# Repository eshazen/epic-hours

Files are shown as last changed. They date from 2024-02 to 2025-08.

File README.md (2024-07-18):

# epic-hours

This is a project to create an electronic sign to display the opening
hours in EPIC.  Basic function is simple:  display open and close time
for each day of the week

There are (14) 8x24 matrix displays for open/close 7 days/week.
These use a special font to fit in the space:

    ten hours:   (blank) or 1
    one hours:   (blank) or 0-9
    ten minutes: (blank) or 0, 3
    one minutes: (blank) or 0

At the top there is a larger matrix, 8x64 which could display
a scrolling banner.

Each 8x8 matrix is driven by a MAX7219 controller IC.
See for example 
[documentation](https://lastminuteengineers.com/max7219-dot-matrix-arduino-tutorial/).

### LED version

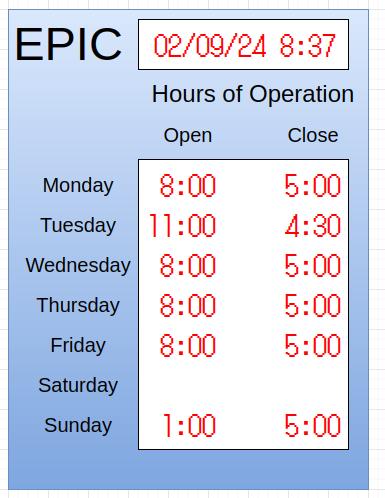
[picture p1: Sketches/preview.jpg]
Preview pixture


The first version should just be "boring" LEDs.  Probably LED matrix,
at least for a banner at the top so messages can be scrolled.
8x8 maxtrix are very popular, so thinking of a 5x7 font.
24 columns work for 12:34 displays.

Need a total of 42+8 = 50 of these.  This is about $100
for modules with MAX7219 included.

Power, 3 digits, quiescent (blanked) = 20mA.

| Intensity | mA  |
|---|-----|
| 3 | 154 |
| 2 | 118 |
| 1 | 80  |

Say 17 groups of 3 @ 150mA = 2.6A @ 5V

Standoffs:

    8   8-32 x 1 inch
	200 6-32 x 1/2 inch less than 0.22" OD

[Preview](Sketches/amazon_8x8.jpg)

### Development Notes

A pcb [multi_display_shield] https://github.com/eshazen/epic-hours/tree/main/KiCAD/multi_display_shield provides power distribution and control for 8
displays.  Each day is organized as a 8x48 single display,
with an 8x64 banner at the top.

For Wifi:  propose to use an ESP32 30-pin dev board.  
See (this page)[https://lastminuteengineers.com/esp32-pinout-reference/]
for some very useful notes.

### Software / Interface

Use Arduino Uno as display controller.  Serial command set:

	T n hh:mm hh:mm   - Time - set weekday time (0,1 = Mon, 2,3 = Tue etc)
	                           for opening and closing
	M text...         - Banner - set banner text.  Scroll if too long
    I n               - Intensity - set intensity n=0-7

ESP32 connects to eduroam WiFi and handles queries such as:

http://10.239.25.67/CMD=M%20Welcome%20to%20EPIC

Everything after the "CMD=" is percent-decoded and sent to the Arduino.

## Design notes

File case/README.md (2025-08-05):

# Enclosure design

Notes for design:

Assembly is a stack of two 3mm acrylic sheets 17-3/4 x 11-5/8 inches.
<br>Spacing varies but is about 1" c-c.
<br>A slot 1-1/24 would do it.

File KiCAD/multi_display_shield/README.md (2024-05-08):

# Multi-Display Shield

This is a very simple Arduino shield which allows driving of up to 8
LED displays based on the MAX7219 or similar SPI-based driver.
The board fans out `MOSI` and `SCK` to all boards using '244 drivers, and
provides separate `CS` signals to each.

## ECOs

* Jumper U1 pin 2-4

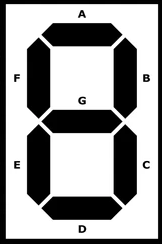
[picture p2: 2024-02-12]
Sketches/7seg.png

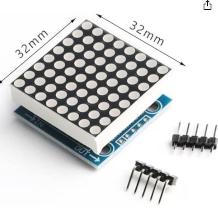
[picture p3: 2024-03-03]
Sketches/amazon_8x8.jpg

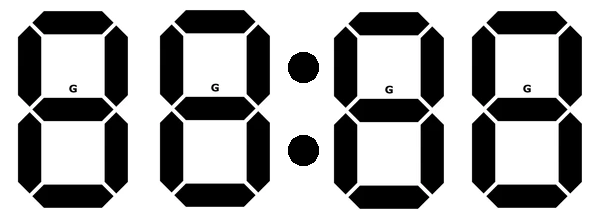
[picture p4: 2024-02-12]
Sketches/7seg-time.png

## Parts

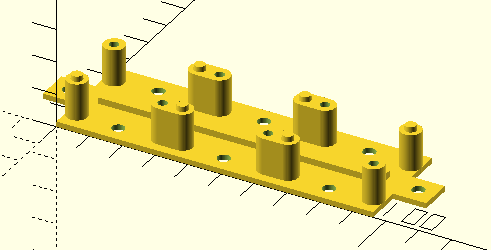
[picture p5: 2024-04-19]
parts/display_standoffs_screenshot.png

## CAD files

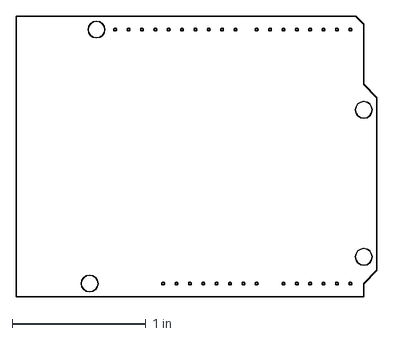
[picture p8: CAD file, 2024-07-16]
parts/Arduino UNO R3 shield - full.dxf
2.70 x 2.10 in

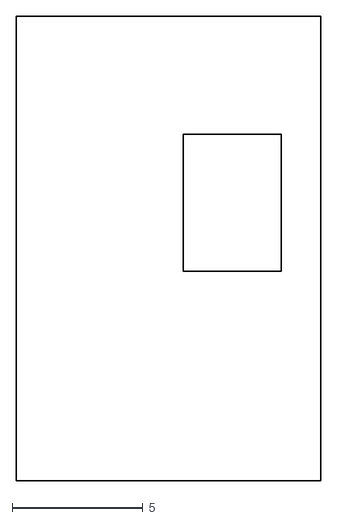
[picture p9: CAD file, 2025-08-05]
case/back_view_outline.dxf
11.6 x 17.8

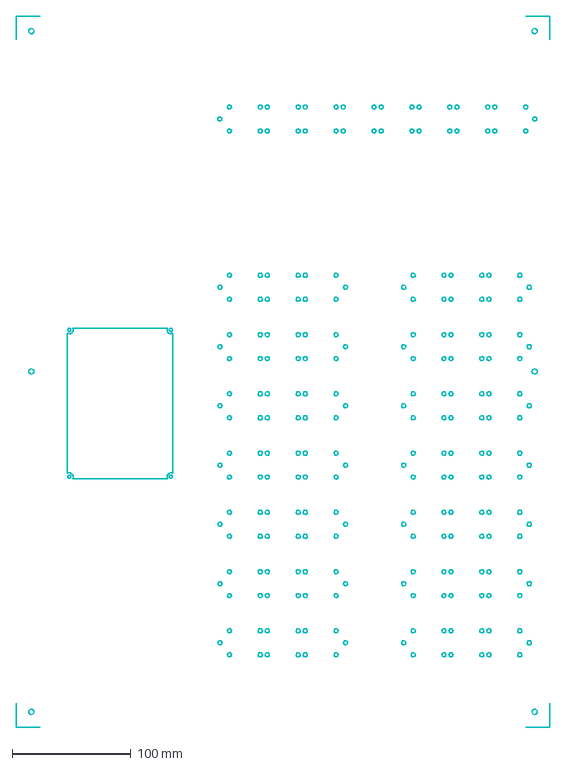
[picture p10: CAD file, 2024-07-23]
laser_cut/cut_back.dxf
450.0 x 600.0 mm

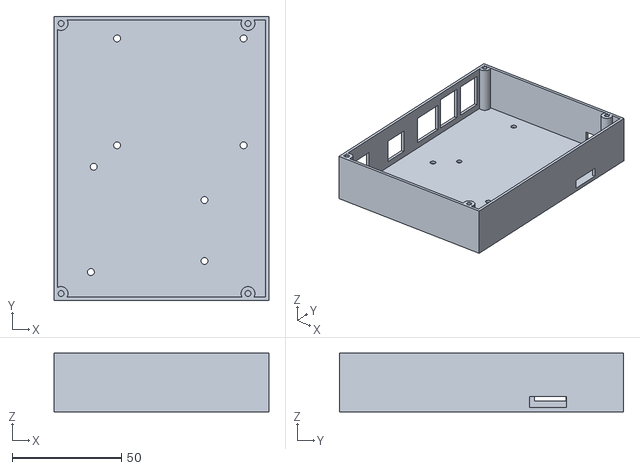
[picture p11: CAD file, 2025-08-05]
parts/rpi_box.stl
98.4 x 130.2 x 27.0

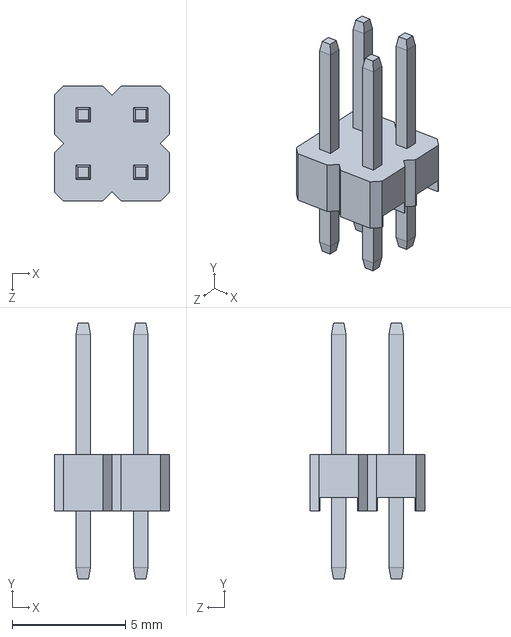
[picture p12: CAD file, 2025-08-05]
parts/rpi_model/2.54 mm DUPONT MALE PIN HEADER, POE, 2X2, RPi4ModelB.SLDPRT
5.08 x 11.3 x 5.08 mm

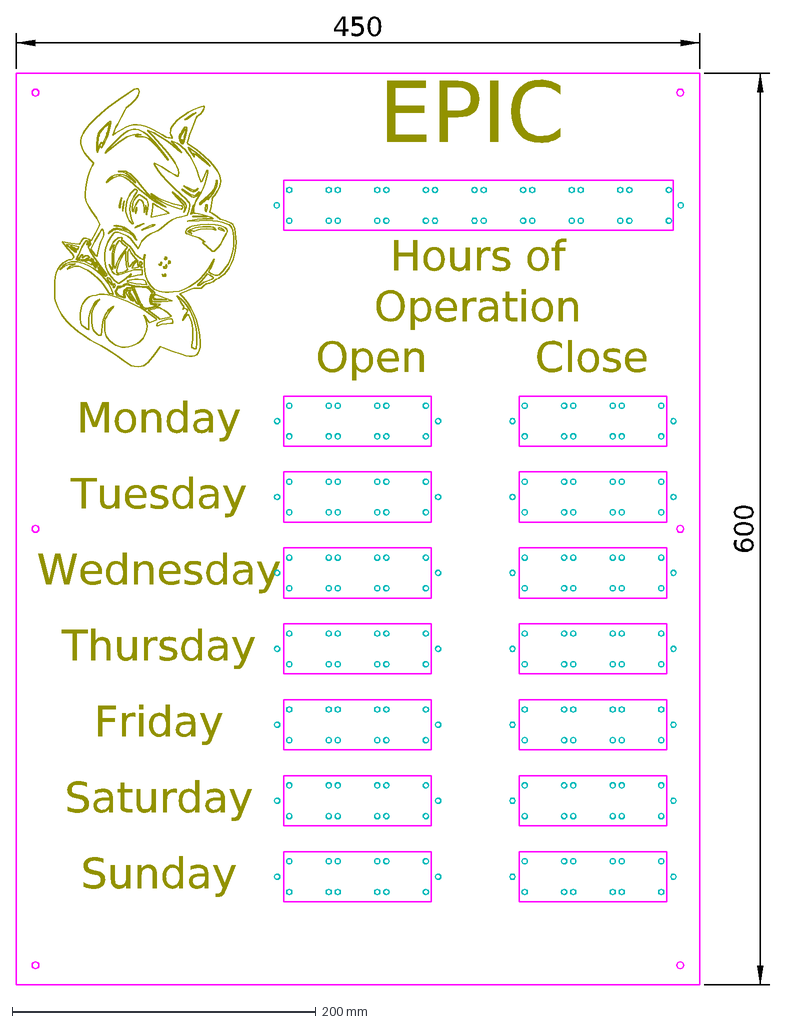
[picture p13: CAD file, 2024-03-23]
Sketches/layout_450x600.dxf
Open
Hours of Operation
Wednesday
Monday
Tuesday
Thursday
Friday
Saturday
Sunday
EPIC
Close
450
600

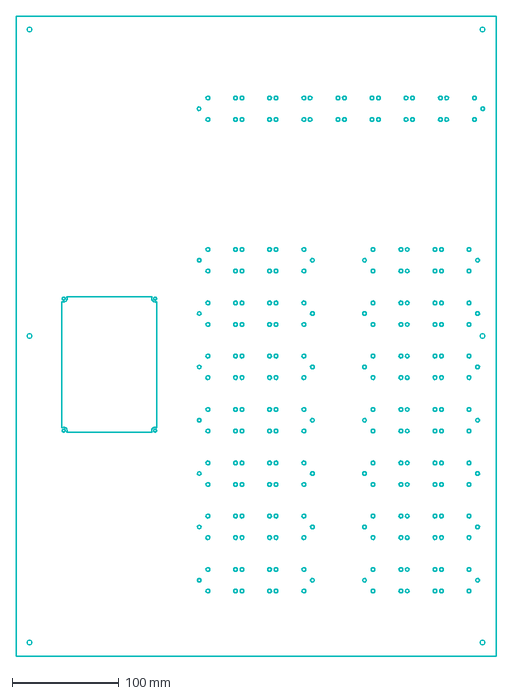
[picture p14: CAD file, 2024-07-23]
laser_cut/cut_back_with_outline.dxf
450.0 x 600.0 mm

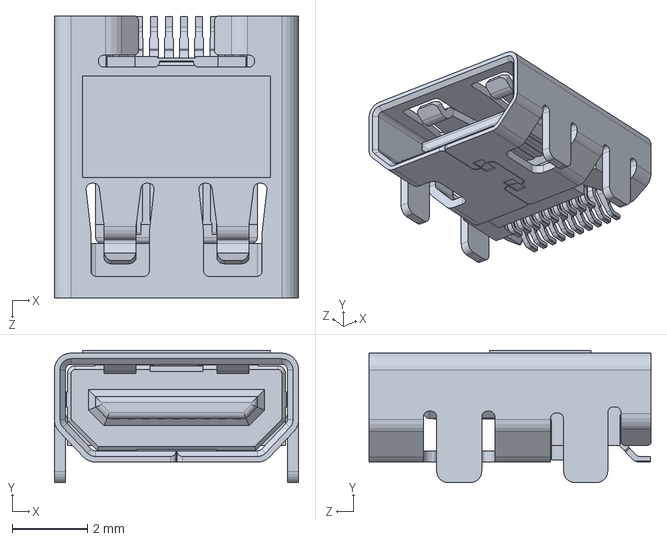
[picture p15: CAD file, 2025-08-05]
parts/rpi_model/Female Micro HDMI Connector, RPi4ModelB.SLDPRT
6.50 x 3.52 x 7.50 mm

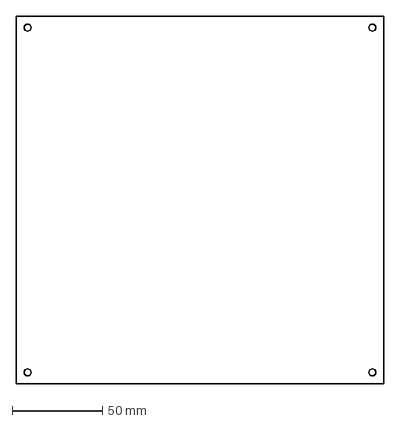
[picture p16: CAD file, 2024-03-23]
Sketches/test_8x8.dxf
203.2 x 203.2 mm

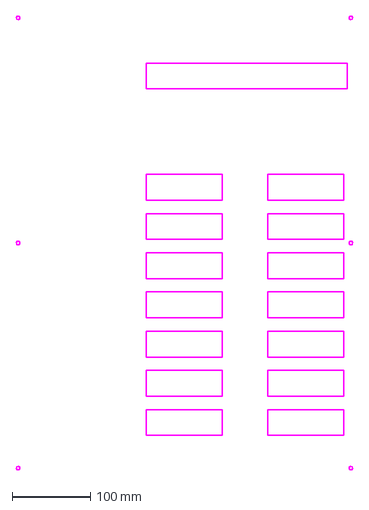
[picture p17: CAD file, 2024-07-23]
laser_cut/cut_front_with_outline.dxf
429.1 x 579.1 mm

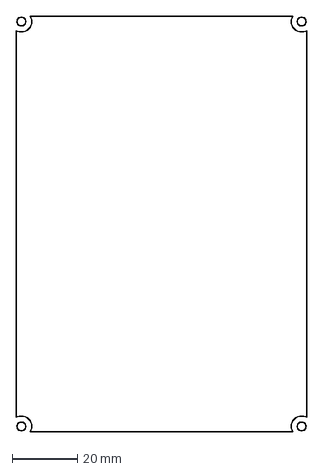
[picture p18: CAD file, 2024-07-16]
parts/arduino_box_opening.dxf
88.9 x 127.0 mm

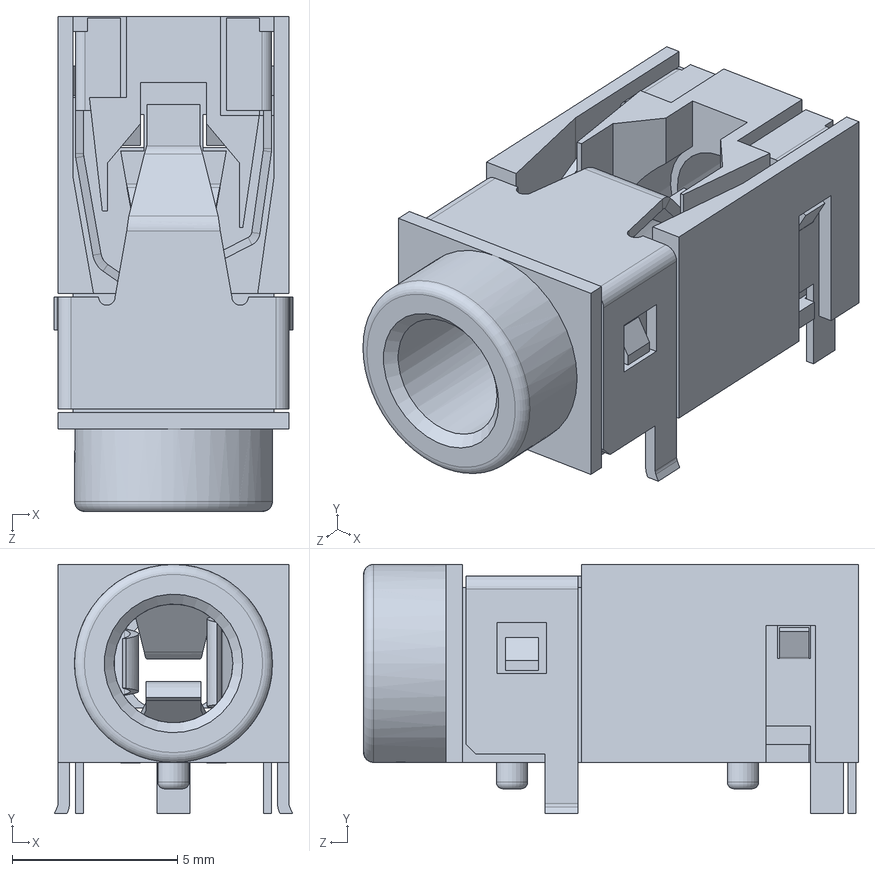
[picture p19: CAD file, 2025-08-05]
parts/rpi_model/Microphone Plug, RPi4ModelB.SLDPRT
7.23 x 7.55 x 15.0 mm

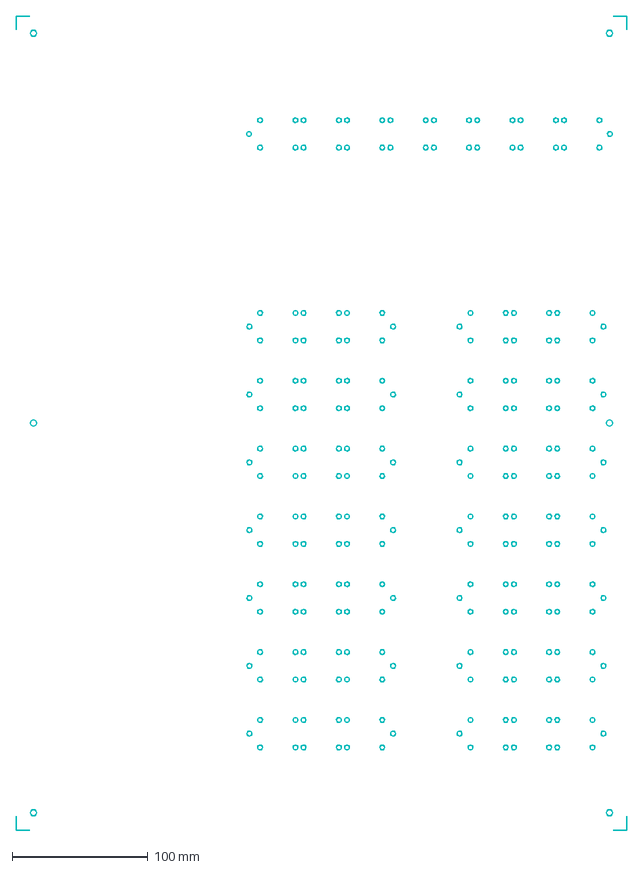
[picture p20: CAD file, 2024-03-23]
Sketches/cut_back.dxf
450.0 x 600.0 mm

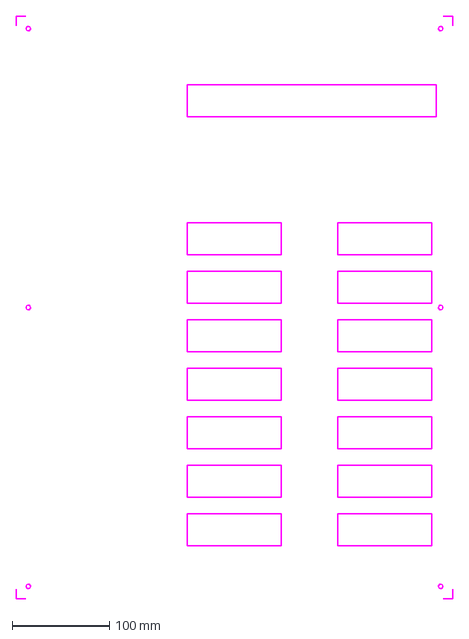
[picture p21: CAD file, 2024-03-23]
laser_cut/cut_front.dxf
450.0 x 600.0 mm

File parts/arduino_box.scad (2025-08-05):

//
// Arduino box, in mm
//

$fn=32;
e=0.1;
mm=25.4;


ardu_x = 0.05*mm;
ardu_y = 0.35*mm;
ardu_dy = 2.25*mm;
ardu_so = 0.125*mm;

flange_w = 0.5*mm;
fh_off = 0.25*mm;
flange_hole_dia = 0.15*mm;
ardu_hole_dia = 0.125*mm;

cavity_wid = 3.5*mm;
cavity_len = 5*mm;
cavity_hgt = 1*mm;
// cavity_hgt = 0.25*mm;

thk = 1.6;

// flange_w = 0.25*mm;
// fh_off = 0.125*mm;
// flange_hole_dia = 0.1*mm;
// ardu_hole_dia = 0.125*mm;
// 
// cavity_wid = 1*mm;
// cavity_len = 1*mm;
// cavity_hgt = 0.5*mm;
// thk = .063*mm;

module hole_at( x, y, d) {
  translate( [x, y, -e])
    cylinder( h=3*mm, d=d);
}

// arduino/shield mounting holes
module ardu_holes( x, y) {
  translate( [x, y, 0]) {
    hole_at( 0.55*mm,  0.1*mm, ardu_hole_dia);
    hole_at( 0.601*mm, 2*mm, ardu_hole_dia);
    hole_at( 2.601*mm, 1.4*mm, ardu_hole_dia);
    hole_at( 2.601*mm, 0.3*mm, ardu_hole_dia);
  }
}

// bottom with mounting holes
module bottom() {
  difference() {
    cube( [cavity_wid, cavity_len, thk]);
    ardu_holes( ardu_x, ardu_y);
    ardu_holes( ardu_x, ardu_y+2.25*mm);
  }
}

// clearance around cutouts
spc = 0.05*mm;

module ardu_cutouts() {
  // USB connector
  translate( [-6, 32+spc, pcb_thk-spc])
    cube( [16, 11.5+2*spc, 10.5+2*spc]);
  // power barrel jack
  color("black") {
    translate( [-6, 3.5+spc, pcb_thk-spc])
      cube( [10, 8.5+2*spc, 11+2*spc]);
  }
}

module ardu_cuts() {
  translate( [ardu_x, ardu_y, thk+ardu_so]) {
    ardu_cutouts();
    translate( [0, ardu_dy, 0])
      ardu_cutouts();
  }
}



// box with cavity
module box() {
  translate( [-thk, -thk, 0]) {
    difference() {
      cube( [cavity_wid+2*thk, cavity_len+2*thk, cavity_hgt+thk]);
      translate( [thk, thk, -e])
	cube( [cavity_wid, cavity_len, cavity_hgt+2*e+thk]);
      ardu_cuts();
    }
  }
}

// flange
max_wid = cavity_wid+2*flange_w;
max_len = cavity_len+2*flange_w;

module flange() {
  translate( [-flange_w, -flange_w, cavity_hgt]) {
    difference() {
      cube( [max_wid, max_len, thk]);
      translate( [flange_w, flange_w, -e])
	cube( [cavity_wid, cavity_len, thk+2*e]);
      hole_at( fh_off, fh_off, flange_hole_dia);
      hole_at( max_wid-fh_off, fh_off, flange_hole_dia);
      hole_at( fh_off, max_len-fh_off, flange_hole_dia);
      hole_at( max_wid-fh_off, max_len-fh_off, flange_hole_dia);
    }
  }
}

so_dia = 0.25*mm;
so_hol = 0.106*mm;

module so_at(x, y) {
  translate( [x, y, thk-e]) {
    difference() {
      cylinder( d=so_dia, h=cavity_hgt);
      translate( [0, 0, thk])
	cylinder( d=so_hol, h=cavity_hgt);
    }
  }
    
}

module standoffs() {
  so_at( thk, thk);
  so_at( cavity_wid-thk, thk);
  so_at( cavity_wid-thk, cavity_len-thk);
  so_at( thk, cavity_len-thk);
}

pcb_thk = 1.6;

module arduino() {
  color("blue")
    linear_extrude( height=pcb_thk)
      scale( [mm, mm, mm]) import("arduino_outline.dxf");
  // USB connector
  translate( [-6, 32, pcb_thk])
    color("gray") cube( [16, 11.5, 10.5]);
  // power barrel jack
  color("black") {
    translate( [-2, 3.5, pcb_thk])
      cube( [3, 8.5, 11]);
    translate( [0, 7.75, 6])
    rotate( [0, 90, 0])
      cylinder( d=8, h=10);
  }
}

module arduinos() {
  translate( [ardu_x, ardu_y, thk+ardu_so]) {
    arduino();
    translate( [0, ardu_dy, 0])
      arduino();
  }
}

module assembly() {
  bottom();
  box();
  standoffs();
}

// projection( cut=true) translate( [0, 0, -10])  
assembly();

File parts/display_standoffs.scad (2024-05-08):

//
// support bracket for 8x8 displays
//

// ToDo:
//   Stiffener ridge down middle
//   Mount tabs at ends
//

$fn = 64;
e = 0.1;
mm = 25.4;

include <post.scad>;

bracket_wid = 32;		/* width of one panel */
bracket_len = 9;		/* bracket width (in Y) */
bracket_hgt = 1.6;		/* thickness of base */

total_hgt = 0.5*mm;		/* overall bracket height (base to pcb) */

// mounting hole diameter
hole_dia = 0.15*mm;

// hole in center of post (for #4 sheet metal screw)
// post_hole = 0.150*mm;
post_hole_dia = 0.11*mm;

// post locations
post_dx = 3;
posts1 = [ [post_dx, 5.9], [32-post_dx, 32-5.9] ];
posts2 = [ [32-post_dx, 5.9], [post_dx, 32-5.9] ];

post_spc_x = 32-2*post_dx;
post_spc_y = 32-2*5.9;

// stiffener
stiff_thk = 5;
stiff_hgt = 2;
stiff_gap = 5;

// end mounting tabs
tab_wid = 0.4*mm;

// mounting hole
module hole_at( x, y, d) {
     translate( [x, y, -e])
	  cylinder( d=d, h=bracket_hgt+2*e);
}

module post_hole( x, y) {
     translate( [x, y, -10])
	  cylinder( h=30, d=post_hole_dia);

}

module tab_at( x, y) {
  translate( [x, y, 0]) {
    difference() {
	 cube( [tab_wid+e, tab_wid, bracket_hgt]);
	 hole_at( tab_wid/2, tab_wid/2, hole_dia);
       }
  }
}


module bracket() {
     difference() {
	  union() {
	       cube( [bracket_wid+e, bracket_wid+e, bracket_hgt]);
	       for( pt = posts1) {
		 post_at( pt.x, pt.y, 1);
	       }
	       for( pt = posts2) {
		 post_at( pt.x, pt.y, 0);
	       }
	  }
	  hole_at( bracket_wid/2, 0.2*mm, hole_dia);
	  hole_at( bracket_wid/2, bracket_wid-0.2*mm, hole_dia);
	  for( pt = posts2) {
	       post_hole( pt.x, pt.y);
	  }
     }
}

// set of <ndigit> brackets
module multi_bracket(ndigit) {
     for( i=[0:ndigit-1]) {
	  translate( [i*bracket_wid, 0, 0])
	       bracket();
     }
     // bridges between standoffs
     if( ndigit > 1) {
	  p1 = posts2[0];
	  p2 = posts1[1];
	  for( i=[0:ndigit-2]) {
	       // offset to bracket
	       translate( [i*bracket_wid, 0, 0]) {
		    // draw the bridge, then re-drill the holes
		    difference() {
			 translate( [p1.x, p1.y-peg_dia/2, 0])
			      cube( [peg_dia, peg_dia, total_hgt]);
			 post_hole( p1.x, p1.y);
			 post_hole( p1.x+2*post_dx, p1.y);
		    }
		    difference() {
			 translate( [p2.x, p2.y-peg_dia/2, 0])
			      cube( [peg_dia, peg_dia, total_hgt]);
			 post_hole( p2.x, p2.y);
			 post_hole( p2.x+2*post_dx, p2.y);
		    }
	       }
	  }
     }

     // stiffener
     translate( [stiff_gap, bracket_wid/2-stiff_thk/2, bracket_hgt-e])
       cube( [ndigit*bracket_wid-2*stiff_gap, stiff_thk, stiff_hgt]);

     // end mounting tabs
     tab_at( -tab_wid, bracket_wid/2-tab_wid/2);
     tab_at( ndigit*bracket_wid-e, bracket_wid/2-tab_wid/2);
       
}

// single peg for testing
module test_peg() {
     difference() {
       post_at( 5, 5, 0);
	  post_hole( 5,5);
     }
     post_at( 5+post_spc_x, 5, 1);
     difference() {
       cube( [bracket_wid+5, 10, bracket_hgt]);
       post_hole( 5, 5);
     }
}

// two multi_bracket() with spacing
module multi_assembly( nb, dx) {
     multi_bracket(nb);
     translate( [dx, 0, 0])
	  multi_bracket(nb);
     translate( [bracket_wid*nb, 0, 0])
	  cube( [dx-nb*bracket_wid, bracket_wid, bracket_hgt]);
}

// projection()
// rotate( [90, 0, 0])
// rotate( [0, 0, 45])
multi_bracket(8);
// multi_assembly( 3, 155);



// test_peg();

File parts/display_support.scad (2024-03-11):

//
// support bracket for 8x8 displays
//

$fn = 64;
e = 0.1;
mm = 25.4;

include <post.scad>;

ndigit = 1;

bracket_wid = 32;		/* width of one panel */
bracket_len = 9;		/* bracket width (in Y) */
bracket_hgt = 1;

total_hgt = 0.5*mm;		/* overall bracket height (back to pcb) */

hole_dia = 0.15*mm;

// mounting hole
module hole_at( x, y) {
     translate( [x, y, -e])
	  cylinder( d=hole_dia, h=bracket_hgt+2*e);
}

module bracket() {
     difference() {
	  cube( [bracket_wid+e, bracket_wid+e, bracket_hgt]);
	  hole_at( bracket_wid/2, 0.2*mm);
	  hole_at( bracket_wid/2, bracket_wid-0.2*mm);
     }
     post_at( 3, 5.9);
     post_at( 32-3, 5.9);
     post_at( 3, 32-5.9);
     post_at( 32-3, 32-5.9);
}

// set of <ndigit> brackets
module multi_bracket() {
     for( i=[0:ndigit-1]) {
	  translate( [i*bracket_wid, 0, 0])
	       bracket();
     }
}

// single peg for testing
module test_peg() {
     post_at( 5, 5);
}

// multi_bracket();


test_peg();

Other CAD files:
parts/#arduino_box_all.dxf
Sketches/cut_back_holes.dxf
parts/post.scad
Sketches/7seg-mech.scad
Sketches/7seg_digit.dxf
Sketches/front_panel.dxf
Sketches/layout_8x8.dxf
parts/8display_standoffs.stl
parts/arduino_box.stl
parts/arduino_box_all.dxf
parts/arduino_box_cutout.dxf
parts/arduino_outline.dxf
parts/display_standoffs.dxf
parts/display_standoffs.stl
parts/display_standoffs_8x.dxf
parts/display_standoffs_side.dxf
parts/display_support.stl
parts/post.stl
parts/rpi_box.scad
parts/rpi_model/2X USB2.0 PORTS, RPi4ModelB.SLDPRT
parts/rpi_model/2X USB3.0 PORTS, RPi4ModelB.SLDPRT
parts/rpi_model/Broadcom BCM2711B0 CPU, RPi4ModelB.SLDPRT
parts/rpi_model/Broadcom BCM54213PE Gigabit Ethernet Transceiver, RPi4ModelB.SLDPRT
parts/rpi_model/Cypress CYW43455 Wireless Module Cover, RPi4ModelB.SLDPRT
parts/rpi_model/Display Connector, RPi4ModelB.SLDPRT
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

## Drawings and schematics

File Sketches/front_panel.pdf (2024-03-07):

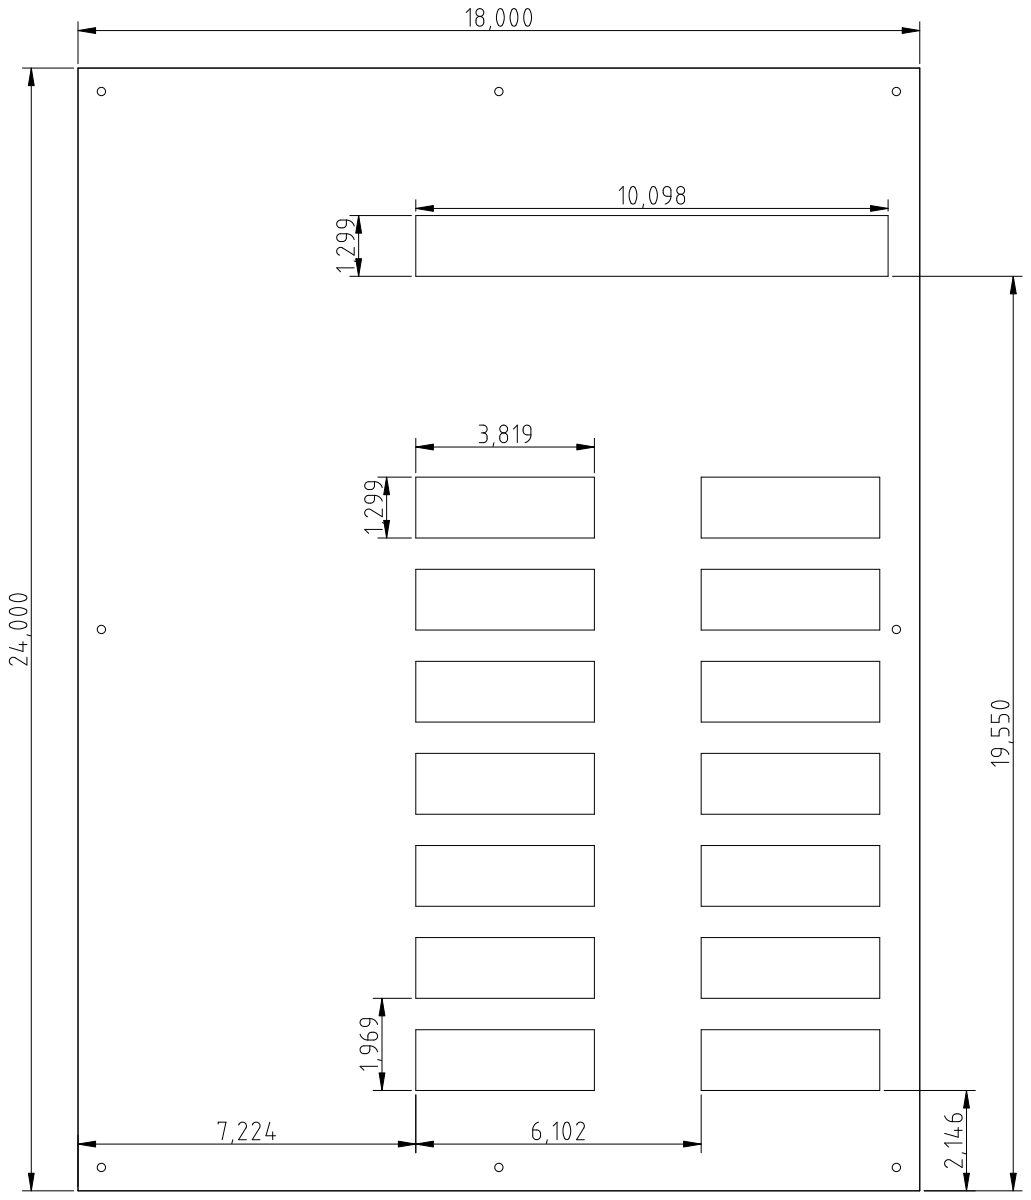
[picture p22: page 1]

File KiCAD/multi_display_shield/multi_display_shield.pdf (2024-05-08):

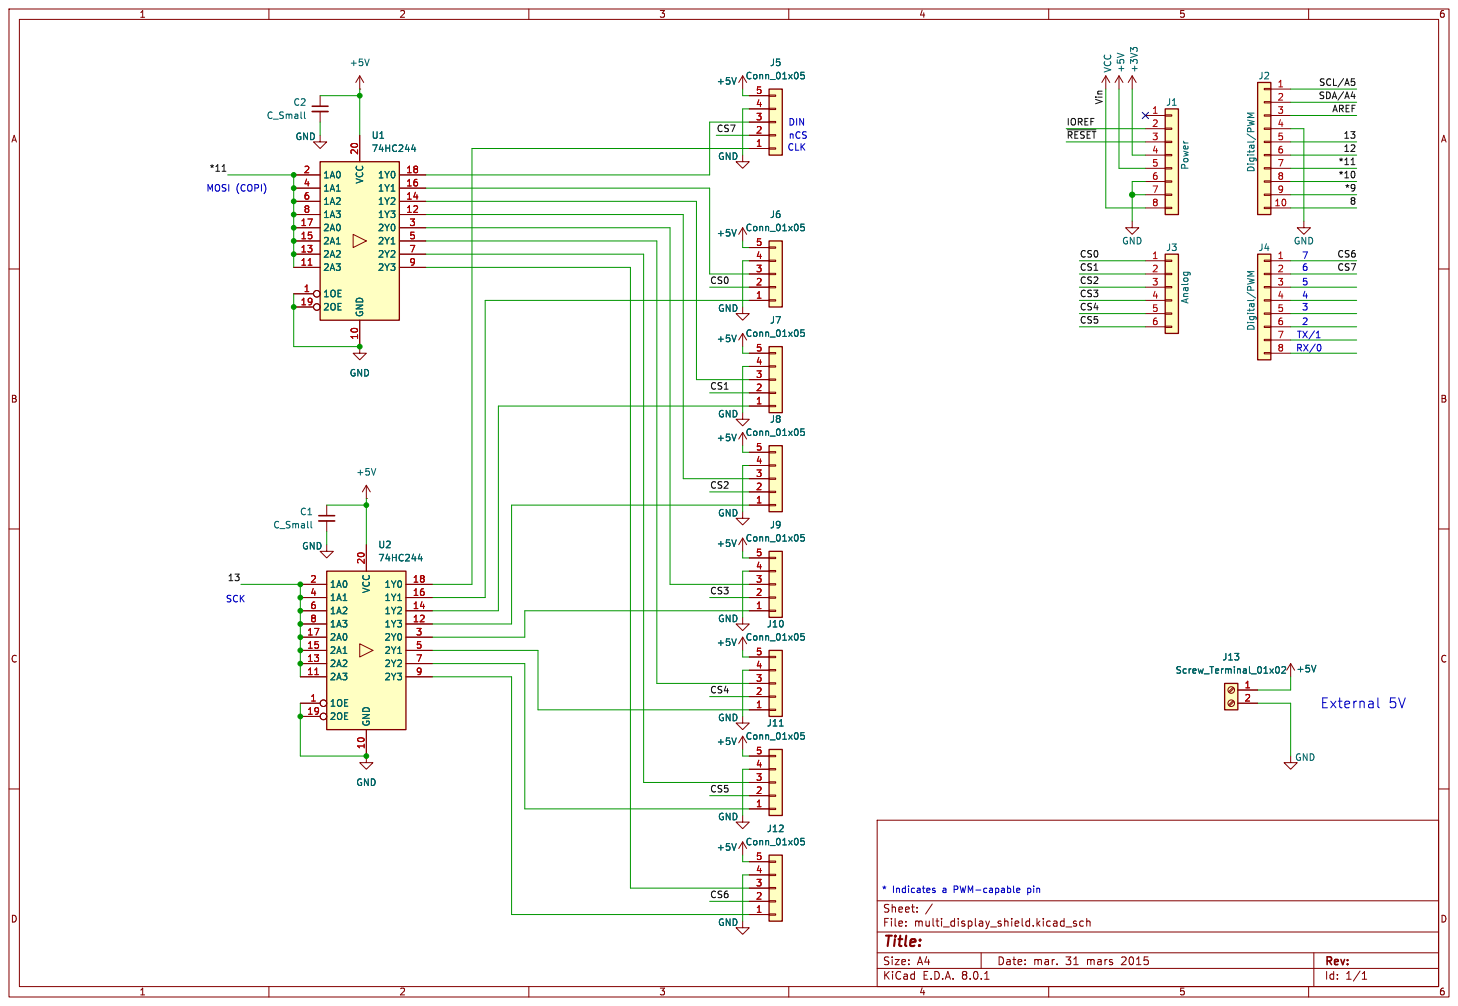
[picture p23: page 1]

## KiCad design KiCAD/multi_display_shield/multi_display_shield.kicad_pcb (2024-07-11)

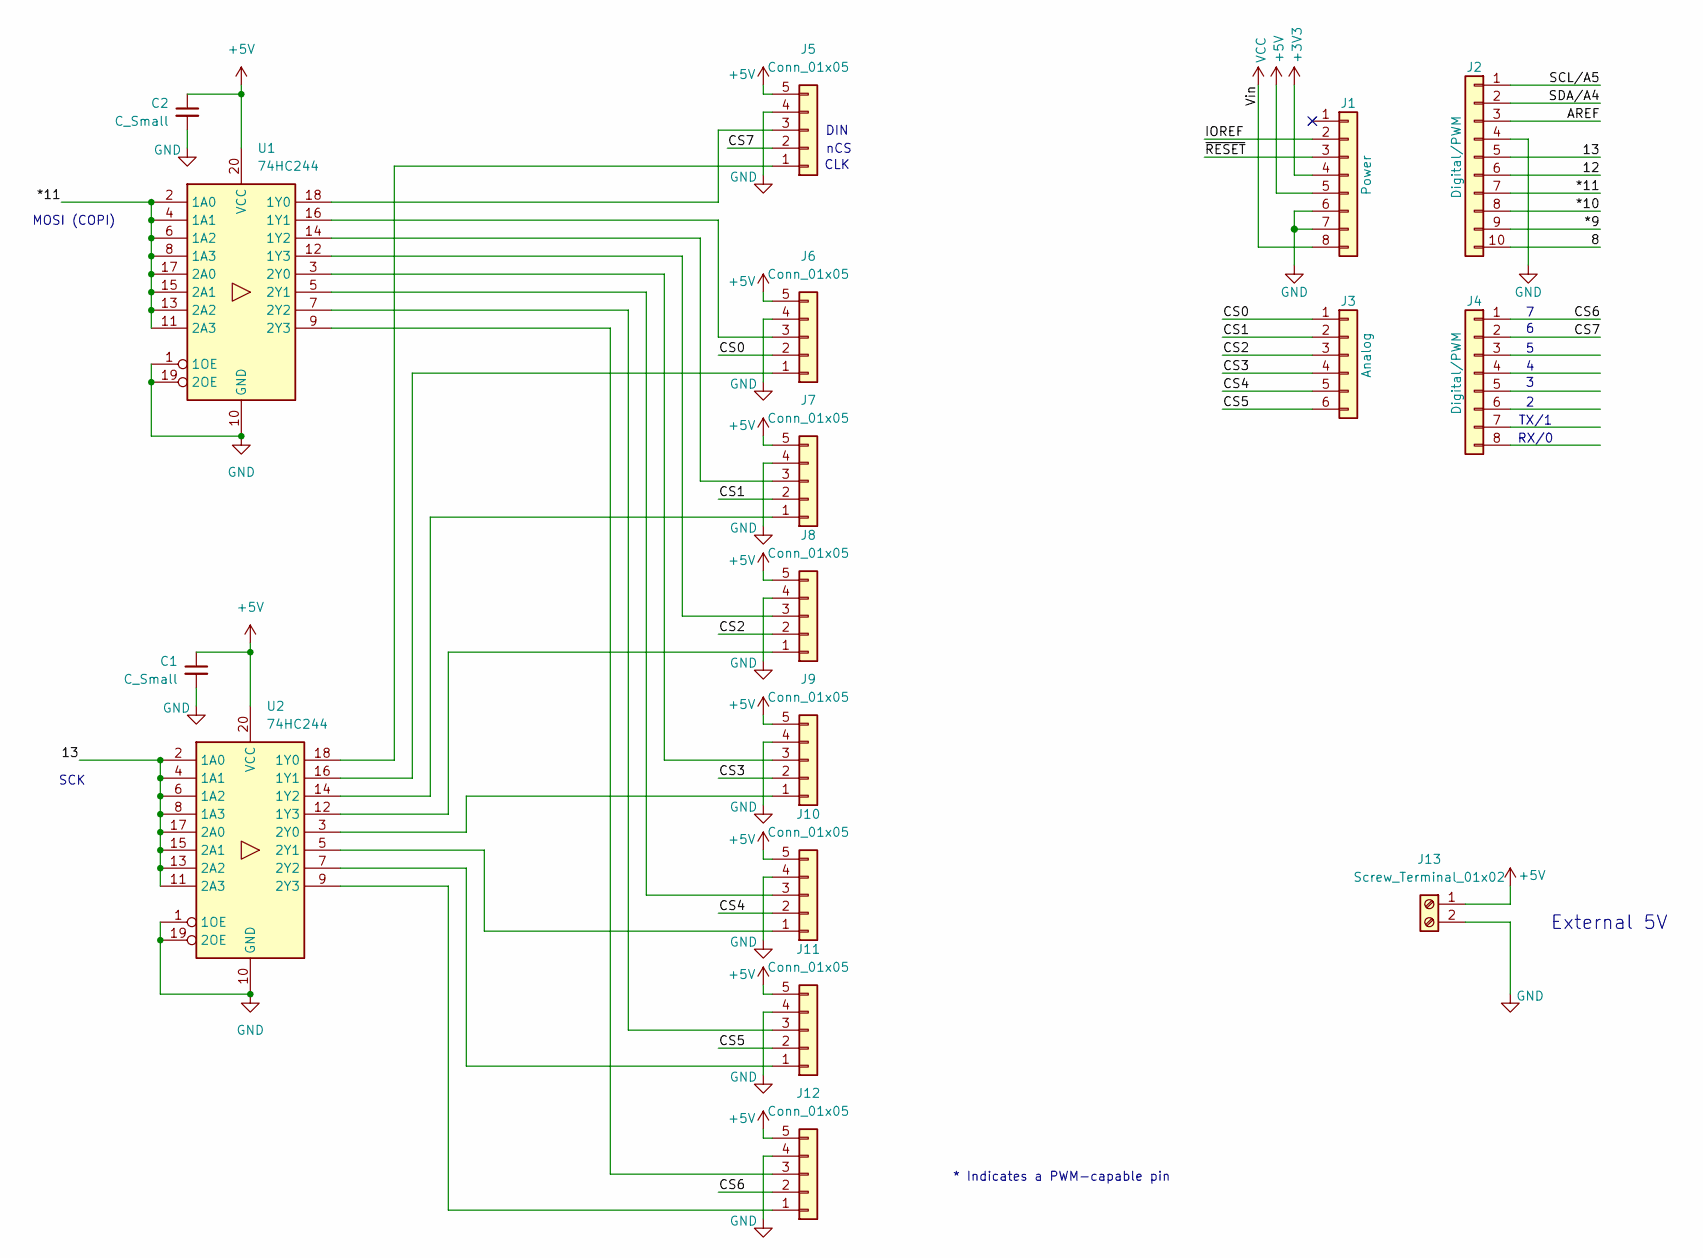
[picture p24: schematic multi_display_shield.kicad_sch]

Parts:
C1, C2: C_Small; C_Rect_L7.0mm_W2.5mm_P5.00mm
J1: Power; PinSocket_1x08_P2.54mm_Vertical
J2: Digital/PWM; PinSocket_1x10_P2.54mm_Vertical
J3: Analog; PinSocket_1x06_P2.54mm_Vertical
J4: Digital/PWM; PinSocket_1x08_P2.54mm_Vertical
J5, J6, J7, J8, J9, J10, J11, J12: Conn_01x05; PinHeader_1x05_P2.54mm_Vertical
J13: Screw_Terminal_01x02; Wago_734-132_1x02_P3.50mm_Vertical
U1, U2: 74HC244; DIP-20_W7.62mm

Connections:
+3V3: J1.4
+5V: C1.1, C2.1, J1.5, J5.5, J6.5, J7.5, J8.5, J9.5, J10.5, J11.5, J12.5, J13.1, U1.20 (VCC), U2.20 (VCC)
/8: J2.10
/12: J2.6
/13: J2.5, U2.2 (1A0), U2.4 (1A1), U2.6 (1A2), U2.8 (1A3), U2.11 (2A3), U2.13 (2A2), U2.15 (2A1), U2.17 (2A0)
/*9: J2.9
/*10: J2.8
/*11: J2.7, U1.2 (1A0), U1.4 (1A1), U1.6 (1A2), U1.8 (1A3), U1.11 (2A3), U1.13 (2A2), U1.15 (2A1), U1.17 (2A0)
/AREF: J2.3
/CS0: J3.1, J6.2
/CS1: J3.2, J7.2
/CS2: J3.3, J8.2
/CS3: J3.4, J9.2
/CS4: J3.5, J10.2
/CS5: J3.6, J11.2
/CS6: J4.1, J12.2
/CS7: J4.2, J5.2
/IOREF: J1.2
/SCL/A5: J2.1
/SDA/A4: J2.2
/~RESET: J1.3
GND: C1.2, C2.2, J1.6, J1.7, J2.4, J5.4, J6.4, J7.4, J8.4, J9.4, J10.4, J11.4, J12.4, J13.2, U1.1 (1OE), U1.10 (GND), U1.19 (2OE), U2.1 (1OE), U2.10 (GND), U2.19 (2OE)
unnamed: J5.1, U2.18 (1Y0)
unnamed: J5.3, U1.18 (1Y0)
unnamed: J6.1, U2.16 (1Y1)
unnamed: J6.3, U1.16 (1Y1)
unnamed: J7.1, U2.14 (1Y2)
unnamed: J7.3, U1.14 (1Y2)
unnamed: J8.1, U2.12 (1Y3)
unnamed: J8.3, U1.12 (1Y3)
unnamed: J9.1, U2.3 (2Y0)
unnamed: J9.3, U1.3 (2Y0)
unnamed: J10.1, U2.5 (2Y1)
unnamed: J10.3, U1.5 (2Y1)
unnamed: J11.1, U2.7 (2Y2)
unnamed: J11.3, U1.7 (2Y2)
unnamed: J12.1, U2.9 (2Y3)
unnamed: J12.3, U1.9 (2Y3)
VCC: J1.8

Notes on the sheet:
CLK
SCK
* Indicates a PWM-capable pin
RX/0
MOSI (COPI)
nCS
DIN
TX/1
External 5V

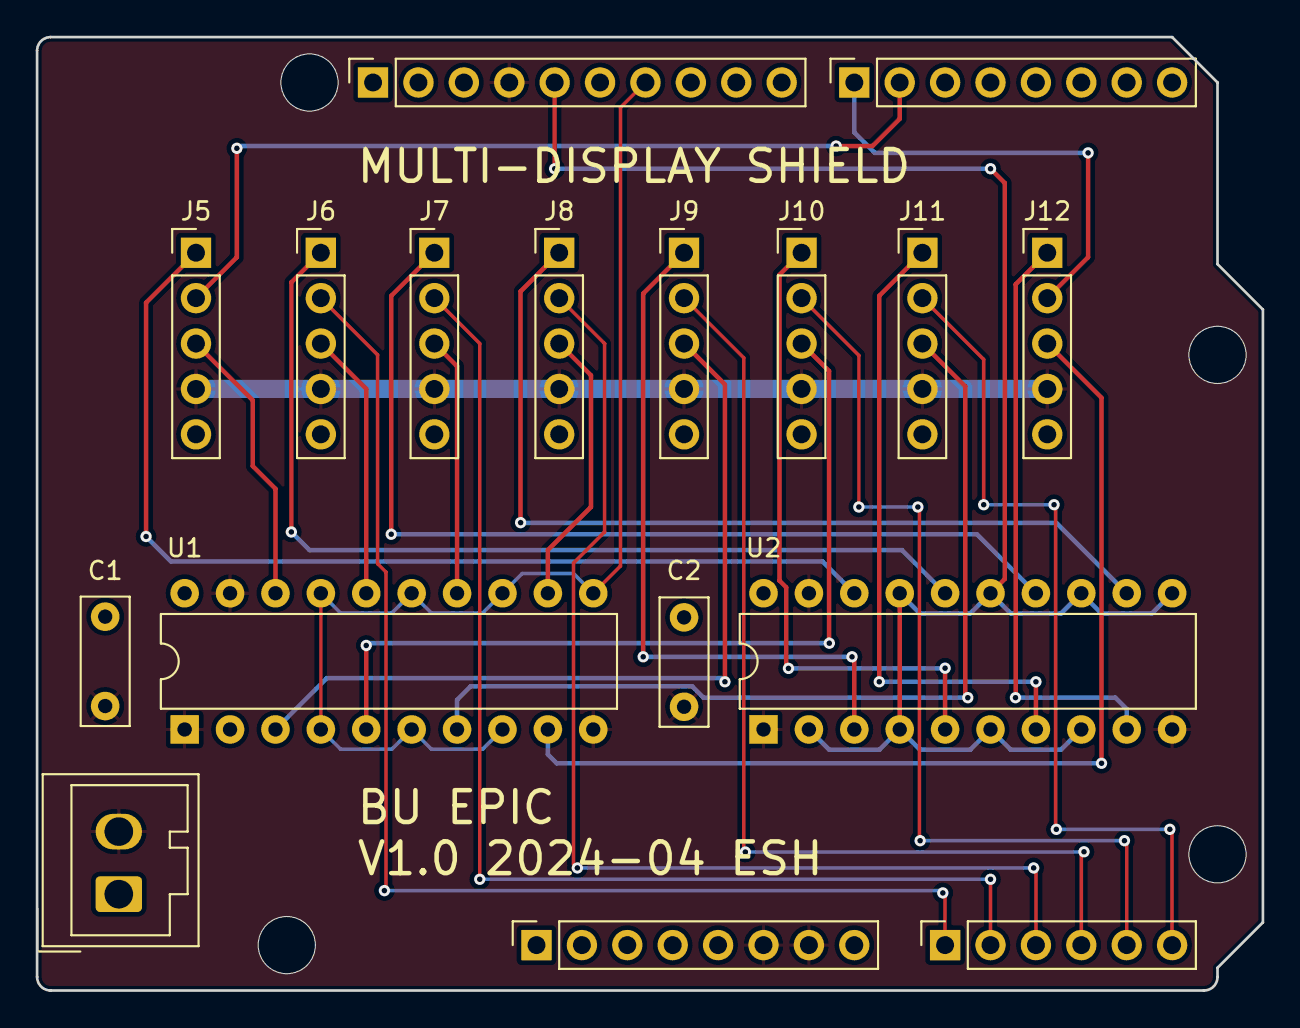
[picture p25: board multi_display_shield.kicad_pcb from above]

Board: 2 copper layers, 68.6 x 53.3 mm, 21 parts (0 on the bottom side), 28 nets.

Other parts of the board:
MH1, MH2, MH3, MH4: MountingHole_3.2mm

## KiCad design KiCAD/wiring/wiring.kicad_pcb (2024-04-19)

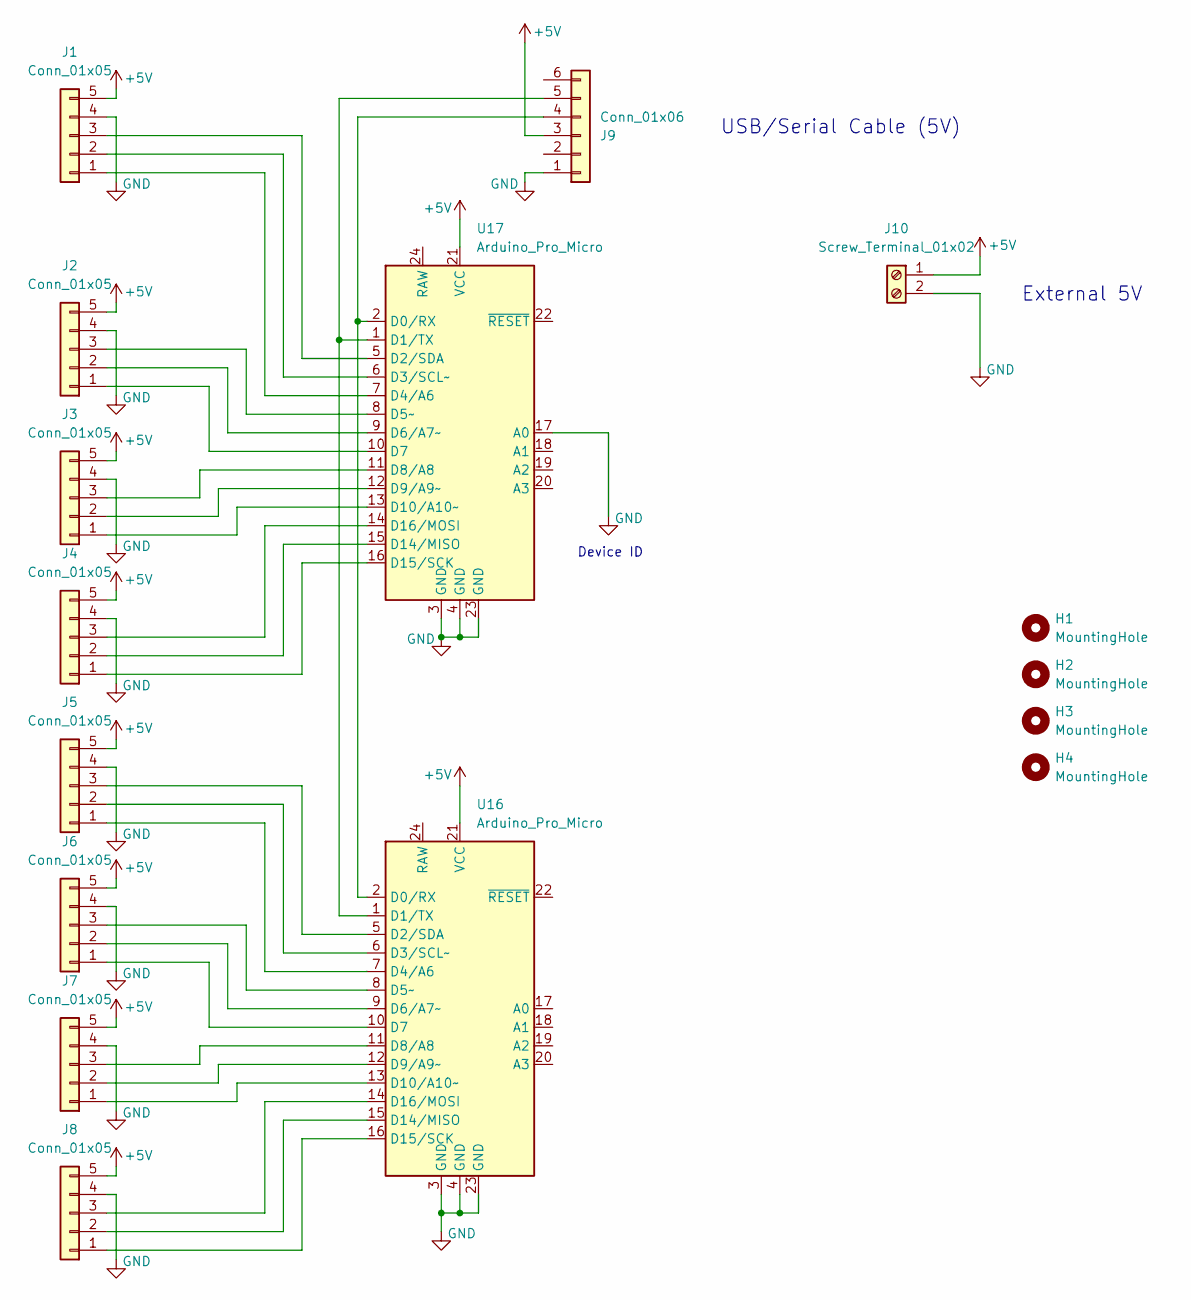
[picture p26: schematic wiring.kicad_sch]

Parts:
H1, H2, H3, H4: MountingHole; MountingHole_4.3mm_M4
J1, J2, J3, J4, J5, J6, J7, J8: Conn_01x05; PinHeader_1x05_P2.54mm_Vertical
J9: Conn_01x06; PinHeader_1x06_P2.54mm_Vertical
J10: Screw_Terminal_01x02; Wago_734-132_1x02_P3.50mm_Vertical
U16, U17: Arduino_Pro_Micro; DIP-24_W15.24mm_LongPads

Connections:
+5V: J1.5, J2.5, J3.5, J4.5, J5.5, J6.5, J7.5, J8.5, J9.3, J10.1, U16.21 (VCC), U17.21 (VCC)
GND: J1.4, J2.4, J3.4, J4.4, J5.4, J6.4, J7.4, J8.4, J9.1, J10.2, U16.3 (GND), U16.4 (GND), U16.23 (GND), U17.3 (GND), U17.4 (GND), U17.17 (A0), U17.23 (GND)
unnamed: J1.1, U17.7 (D4/A6)
unnamed: J1.2, U17.6 (D3/SCL~)
unnamed: J1.3, U17.5 (D2/SDA)
unnamed: J2.1, U17.10 (D7)
unnamed: J2.2, U17.9 (D6/A7~)
unnamed: J2.3, U17.8 (D5~)
unnamed: J3.1, U17.13 (D10/A10~)
unnamed: J3.2, U17.12 (D9/A9~)
unnamed: J3.3, U17.11 (D8/A8)
unnamed: J4.1, U17.16 (D15/SCK)
unnamed: J4.2, U17.15 (D14/MISO)
unnamed: J4.3, U17.14 (D16/MOSI)
unnamed: J5.1, U16.7 (D4/A6)
unnamed: J5.2, U16.6 (D3/SCL~)
unnamed: J5.3, U16.5 (D2/SDA)
unnamed: J6.1, U16.10 (D7)
unnamed: J6.2, U16.9 (D6/A7~)
unnamed: J6.3, U16.8 (D5~)
unnamed: J7.1, U16.13 (D10/A10~)
unnamed: J7.2, U16.12 (D9/A9~)
unnamed: J7.3, U16.11 (D8/A8)
unnamed: J8.1, U16.16 (D15/SCK)
unnamed: J8.2, U16.15 (D14/MISO)
unnamed: J8.3, U16.14 (D16/MOSI)
unnamed: J9.4, U16.2 (D0/RX), U17.2 (D0/RX)
unnamed: J9.5, U16.1 (D1/TX), U17.1 (D1/TX)

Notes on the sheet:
Device ID
External 5V
USB/Serial Cable (5V)

Board: 2 copper layers, 16 parts (0 on the bottom side), 28 nets, no tracks yet.

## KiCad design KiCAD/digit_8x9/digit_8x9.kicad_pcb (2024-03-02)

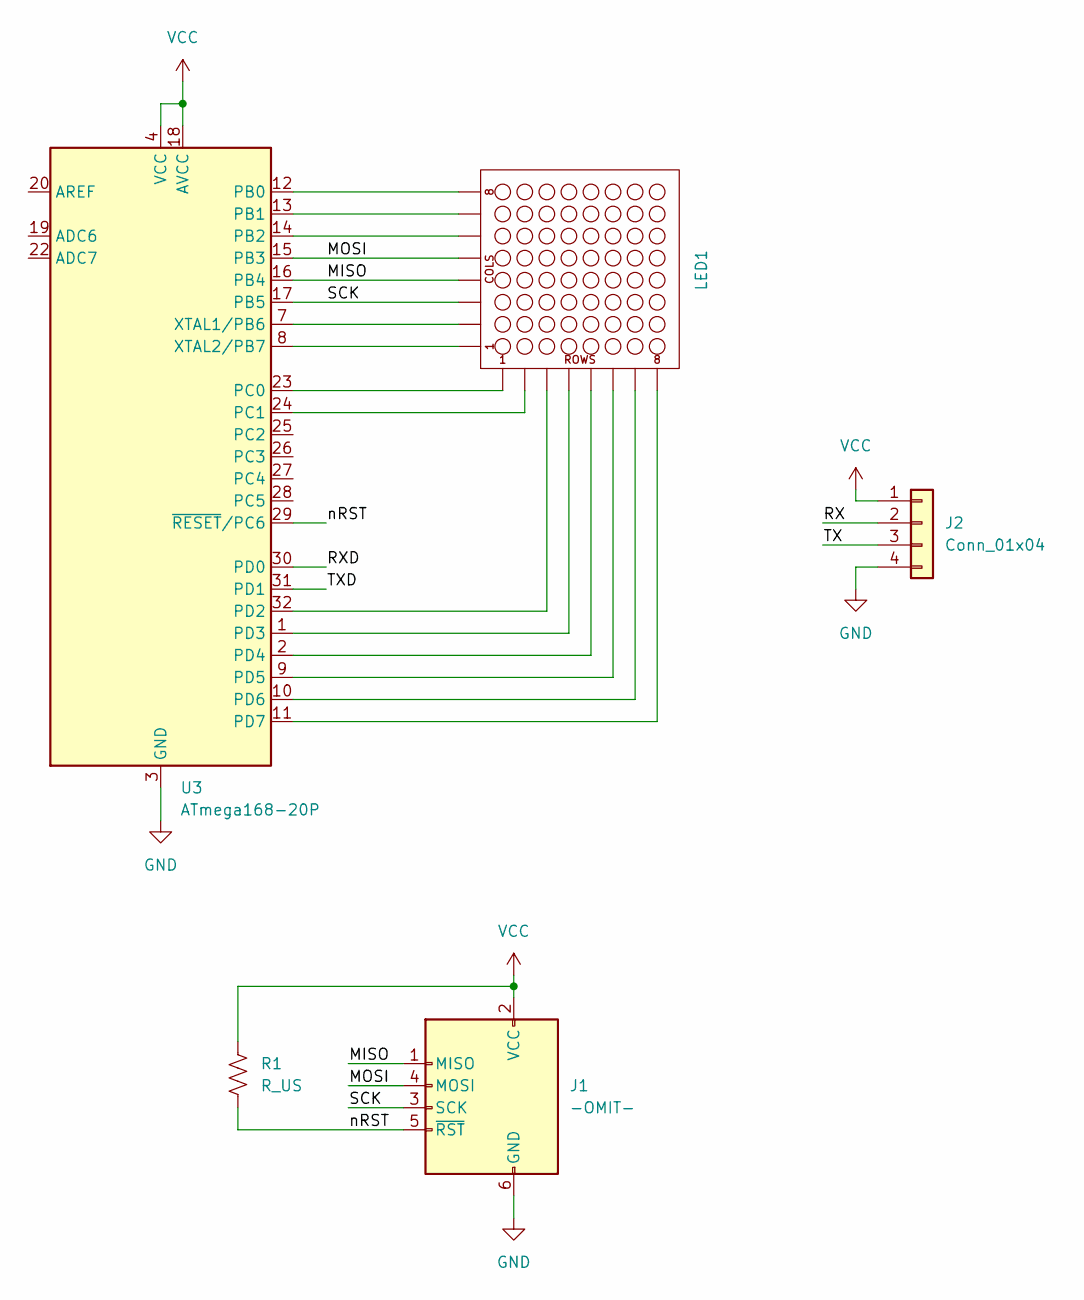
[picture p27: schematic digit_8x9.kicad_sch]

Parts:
J1: -OMIT-; PinHeader_2x03_P2.54mm_Vertical
J2: Conn_01x04; PinHeader_1x04_P2.54mm_Vertical
LED1: Adafruit_32mm_8x8
R1: R_US; R_0805_2012Metric_Pad1.20x1.40mm_HandSolder
U3: ATmega168-20P; TQFP-32_7x7mm_P0.8mm

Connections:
/MISO: J1.1 (MISO), LED1.10 (COL4), U3.16 (PB4)
/MOSI: J1.4 (MOSI), LED1.6 (COL5), U3.15 (PB3)
/RX: J2.2
/RXD: U3.30 (PD0)
/SCK: J1.3 (SCK), LED1.4 (COL3), U3.17 (PB5)
/TX: J2.3
/TXD: U3.31 (PD1)
/nRST: J1.5 (~RST), R1.2, U3.29 (~RESET/PC6)
GND: J1.6 (GND), J2.4, U3.3 (GND), U3.5 (GND), U3.21 (GND)
unnamed: LED1.13 (COL1), U3.8 (XTAL2/PB7)
unnamed: LED1.3 (COL2), U3.7 (XTAL1/PB6)
unnamed: LED1.11 (COL6), U3.14 (PB2)
unnamed: LED1.15 (COL7), U3.13 (PB1)
unnamed: LED1.16 (COL8), U3.12 (PB0)
unnamed: LED1.9 (ROW1), U3.23 (PC0)
unnamed: LED1.14 (ROW2), U3.24 (PC1)
unnamed: LED1.8 (ROW3), U3.32 (PD2)
unnamed: LED1.12 (ROW4), U3.1 (PD3)
unnamed: LED1.1 (ROW5), U3.2 (PD4)
unnamed: LED1.7 (ROW6), U3.9 (PD5)
unnamed: LED1.2 (ROW7), U3.10 (PD6)
unnamed: LED1.5 (ROW8), U3.11 (PD7)
VCC: J1.2 (VCC), J2.1, R1.1, U3.4 (VCC), U3.6 (VCC), U3.18 (AVCC)

Board: 2 copper layers, 5 parts (4 on the bottom side), 19 nets, no tracks yet.

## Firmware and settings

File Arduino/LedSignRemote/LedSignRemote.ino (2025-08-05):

//
// Control firmware for the EPIC LED sign
//   8 display chains, first 6 with (6) 8x8 segments, last one with (8) 8x8 segments
// Expect serial commands at 9600 baud on hardware UART:
//
// M <marquee text>          update the top-line scrolled message (80 char max)
// T n hh:mm hh:mm           update open/close times for a day (0-7)
// I n                       set intensity to n (0-10)
//
// Note that times must be 12-hour (there isn't room for a digit "2" in the 1st position)
//

#include <LEDMatrixDriver.hpp>

const uint8_t cs_pins[] = { 6, A0, A1, A2, A3, A4, A5, 7 };
#define NDISP (sizeof(cs_pins)/sizeof(cs_pins[0]))
#define TOPDISP (NDISP-1)

// Number of 8x8 segments you are connecting
const int LEDMATRIX_SEGMENTS = 6; // weekday displays
const int TOPMATRIX_SEGMENTS = 8; // top display

const int TOPMATRIX_WIDTH    = TOPMATRIX_SEGMENTS * 8;
const int LEDMATRIX_WIDTH    = LEDMATRIX_SEGMENTS * 8;

// The LEDMatrixDriver class instance
// LEDMatrixDriver lmd(LEDMATRIX_SEGMENTS, LEDMATRIX_CS_PIN);
LEDMatrixDriver* lmdp[NDISP];

// Buffer to hours display
char t_open[6];
char t_clos[6];
  
// command input buffer
char buff[80];

// token pointers
char *tokn[5];

// scrolling text buffer
char scrolling[80];

// Top line marquee speed (lower nubmers = faster)
const int ANIM_DELAY = 30;

// one framebuffer
uint8_t fb[TOPMATRIX_SEGMENTS*8];

// Time update delay for demo (1 sec)
const int TIME_DELAY = 1000;

unsigned long last_ms;
unsigned long time_ms;

uint8_t dayn = 0;		// day number for update
uint8_t utime = 0;		// update flag for times
uint8_t nscr = 0;		// update flag for scrolling
uint8_t brgt = 0;		// brightness

byte font_char[9];		// buffer for one font character

int ntok;

// Special 5x7 font with digits 0-9 only, space
// variable width, width is first byte
// ** used only for weekday times **
// Font stored in flash
const byte font[12][8] PROGMEM = { { 5, 0x70,0x88,0x88,0x88,0x88,0x88,0x70}, // 0
		     { 3, 0x40,0xc0,0x40,0x40,0x40,0x40,0xe0}, // 1
		     { 5, 0x70,0x88,0x08,0x10,0x20,0x40,0xf8}, // 2
		     { 5, 0x70,0x88,0x08,0x70,0x08,0x88,0x70}, // 3
		     { 5, 0x10,0x30,0x50,0x90,0xf8,0x10,0x10}, // 4
		     { 5, 0xf8,0x80,0x80,0xf0,0x08,0x08,0xf0}, // 5
		     { 5, 0x70,0x88,0x80,0xf0,0x88,0x88,0x70}, // 6
		     { 5, 0xf8,0x08,0x10,0x20,0x20,0x40,0x40},  // 7
		     { 5, 0x70,0x88,0x88,0x70,0x88,0x88,0x70}, // 8
		     { 5, 0x70,0x88,0x88,0x78,0x08,0x08,0x70}, // 9
		     { 5, 0, 0, 0, 0, 0, 0, 0}, // space
		     { 1, 0x00,0x80,0x80,0x00,0x80,0x80,0x00} // :
};

 // This is the font definition. You can use http://gurgleapps.com/tools/matrix to create your own font or sprites.
 // If you like the font feel free to use it. I created it myself and donate it to the public domain.
 const byte bigfont[95][8] PROGMEM = { {0,0,0,0,0,0,0,0},           // SPACE [32]
                      {0x10,0x18,0x18,0x18,0x18,0x00,0x18,0x18}, // EXCL [33]
                      {0x28,0x28,0x08,0x00,0x00,0x00,0x00,0x00}, // QUOT
                      {0x00,0x0a,0x7f,0x14,0x28,0xfe,0x50,0x00}, // #
                      {0x10,0x38,0x54,0x70,0x1c,0x54,0x38,0x10}, // $
                      {0x00,0x60,0x66,0x08,0x10,0x66,0x06,0x00}, // %
                      {0,0,0,0,0,0,0,0}, // &
                      {0x00,0x10,0x18,0x18,0x08,0x00,0x00,0x00}, // '
                      {0x02,0x04,0x08,0x08,0x08,0x08,0x08,0x04}, // (
                      {0x40,0x20,0x10,0x10,0x10,0x10,0x10,0x20}, // )
                      {0x00,0x10,0x54,0x38,0x10,0x38,0x54,0x10}, // *
                      {0x00,0x08,0x08,0x08,0x7f,0x08,0x08,0x08}, // +
                      {0x00,0x00,0x00,0x00,0x00,0x18,0x18,0x08}, // COMMA
                      {0x00,0x00,0x00,0x00,0x7e,0x00,0x00,0x00}, // -
                      {0x00,0x00,0x00,0x00,0x00,0x00,0x06,0x06}, // DOT
                      {0x00,0x04,0x04,0x08,0x10,0x20,0x40,0x40}, // /
                      {0x00,0x38,0x44,0x4c,0x54,0x64,0x44,0x38}, // 0
                      {0x04,0x0c,0x14,0x24,0x04,0x04,0x04,0x04}, // 1
                      {0x00,0x30,0x48,0x04,0x04,0x38,0x40,0x7c}, // 2
                      {0x00,0x38,0x04,0x04,0x18,0x04,0x44,0x38}, // 3
                      {0x00,0x04,0x0c,0x14,0x24,0x7e,0x04,0x04}, // 4
                      {0x00,0x7c,0x40,0x40,0x78,0x04,0x04,0x38}, // 5
                      {0x00,0x38,0x40,0x40,0x78,0x44,0x44,0x38}, // 6
                      {0x00,0x7c,0x04,0x04,0x08,0x08,0x10,0x10}, // 7
                      {0x00,0x3c,0x44,0x44,0x38,0x44,0x44,0x78}, // 8
                      {0x00,0x38,0x44,0x44,0x3c,0x04,0x04,0x78}, // 9
                      {0x00,0x18,0x18,0x00,0x00,0x18,0x18,0x00}, // :
                      {0x00,0x18,0x18,0x00,0x00,0x18,0x18,0x08}, // ;
                      {0x00,0x10,0x20,0x40,0x80,0x40,0x20,0x10}, // <
                      {0x00,0x00,0x7e,0x00,0x00,0xfc,0x00,0x00}, // =
                      {0x00,0x08,0x04,0x02,0x01,0x02,0x04,0x08}, // >
                      {0x00,0x38,0x44,0x04,0x08,0x10,0x00,0x10}, // ?
                      {0x00,0x30,0x48,0xba,0xba,0x84,0x78,0x00}, // @
                      {0x00,0x1c,0x22,0x42,0x42,0x7e,0x42,0x42}, // A
                      {0x00,0x78,0x44,0x44,0x78,0x44,0x44,0x7c}, // B
                      {0x00,0x3c,0x44,0x40,0x40,0x40,0x44,0x7c}, // C
                      {0x00,0x7c,0x42,0x42,0x42,0x42,0x44,0x78}, // D
                      {0x00,0x78,0x40,0x40,0x70,0x40,0x40,0x7c}, // E
                      {0x00,0x7c,0x40,0x40,0x78,0x40,0x40,0x40}, // F
                      {0x00,0x3c,0x40,0x40,0x5c,0x44,0x44,0x78}, // G
                      {0x00,0x42,0x42,0x42,0x7e,0x42,0x42,0x42}, // H
                      {0x00,0x7c,0x10,0x10,0x10,0x10,0x10,0x7e}, // I
                      {0x00,0x7e,0x02,0x02,0x02,0x02,0x04,0x38}, // J
                      {0x00,0x44,0x48,0x50,0x60,0x50,0x48,0x44}, // K
                      {0x00,0x40,0x40,0x40,0x40,0x40,0x40,0x7c}, // L
                      {0x00,0x82,0xc6,0xaa,0x92,0x82,0x82,0x82}, // M
                      {0x00,0x42,0x42,0x62,0x52,0x4a,0x46,0x42}, // N
                      {0x00,0x3c,0x42,0x42,0x42,0x42,0x44,0x38}, // O
                      {0x00,0x78,0x44,0x44,0x48,0x70,0x40,0x40}, // P
                      {0x00,0x3c,0x42,0x42,0x52,0x4a,0x44,0x3a}, // Q
                      {0x00,0x78,0x44,0x44,0x78,0x50,0x48,0x44}, // R
                      {0x00,0x38,0x40,0x40,0x38,0x04,0x04,0x78}, // S
                      {0x00,0x7e,0x90,0x10,0x10,0x10,0x10,0x10}, // T
                      {0x00,0x42,0x42,0x42,0x42,0x42,0x42,0x3e}, // U
                      {0x00,0x42,0x42,0x42,0x42,0x44,0x28,0x10}, // V
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
                       // (the font does not contain any lower case letters. you can add your own.)
                   };    // {}, //



//
// split a comma-separated (or other delim) string to up to siz tokens
// return token count
//
// NOTE:  overwrites string by terminating tokens with '\0'
#
#define SPLIT_DELIM ' '

int split( char *str, char **toks, int siz) {
  char *p = str;		/* point to start of string */
  int nt = 0;			/* token counter */
  
  while( *p && nt < siz) {  /* loop to string end or over siz */
    toks[nt++] = p;	    /* always point to token here */
    while( *p && *p != SPLIT_DELIM)	/* skip over non-delims */
      ++p;
    // check if delim or end of string
    if( *p) {  // non-null char must be delim
      // check for empty token
      if( !p[1])	    /* is this the end of the string */
	toks[nt++] = p+1;   /* yes, add pointer to enpty token */
      *p = '\0';	    /* and terminate it */
      ++p;
    }
  }
  return nt;
}

uint8_t hour = 12;
uint8_t minu = 34;

int xs=0;


void setup() {
  for( uint8_t i=0; i<NDISP; i++) {
    if( i == TOPDISP)
      // flags=7 to invert the display, 0 for normal
      lmdp[i] = new LEDMatrixDriver(TOPMATRIX_SEGMENTS, cs_pins[i], 7, fb);
    else
      lmdp[i] = new LEDMatrixDriver(LEDMATRIX_SEGMENTS, cs_pins[i], 7, fb);
    // init the display
    lmdp[i]->setEnabled(true);
    lmdp[i]->setIntensity(0);   // 0 = low, 10 = high
    lmdp[i]->clear();
    lmdp[i]->display();
  }
  last_ms = millis();
  time_ms = millis();

  Serial.begin(9600);
  Serial.setTimeout(10000);

  strcpy_P( scrolling, PSTR("Welcome to EPIC!"));

  // blank the top display
  lmdp[TOPDISP]->clear();
  lmdp[TOPDISP]->display();

  delay(100);

  strcpy_P( t_open, PSTR("9:00"));
  strcpy_P( t_clos, PSTR("5:00"));
  
  // initial update of all displays
  for( uint8_t i=0; i<NDISP-1; i++) {
    lmdp[i]->clear();
    lmdp[i]->display();
    delay(100);
    *t_open = '0'+i;
    *t_clos = '0'+(7-i);
    drawStringN(lmdp[i], t_open, 5, 0, 0);
    drawStringN(lmdp[i], t_clos, 5, 24, 0);
    lmdp[i]->display();
  }
}

// overwrite first control character with \0
void chomp( char *buff) {
  while( *buff && !iscntrl( *buff))
    ++buff;
  *buff = '\0';
}


void loop()
{
  unsigned long ms_now = millis();

  // check for characters
  if( Serial.available()) {
    // read a complete line
    memset( buff, 0, sizeof(buff));
    Serial.readBytesUntil( '\n', buff, sizeof(buff)-1);
    chomp( buff);
    switch( toupper( buff[0])) {

    case 'M':			// set marquee text
      strcpy( scrolling, buff+2);
      nscr = 1;
      break;

    case 'T':			// update times for a day
      //      int split( char *str, char **toks, int siz) {
      ntok = split( buff, tokn, sizeof(tokn)/sizeof(tokn[0]));
      if( ntok == 4) {
	dayn = *tokn[1]-'0';
	memset( t_open, 0, sizeof(t_open));
	strncpy( t_open, tokn[2], sizeof(t_open));
	memset( t_clos, 0, sizeof(t_clos));
	strncpy( t_clos, tokn[3], sizeof(t_clos));
	utime = 1;
      }
      break;

    case 'I':			// set intensity
      brgt = buff[2]-'0';
      for( int i=0; i<NDISP; i++)
	      lmdp[i]->setIntensity(brgt);   // 0 = low, 10 = high

      break;
    }
  }

  // check for scrolling display update
  
  if( ms_now - last_ms > ANIM_DELAY) {
    last_ms = ms_now;

    if( nscr) {
      nscr = 0;
      lmdp[TOPDISP]->clear();
      lmdp[TOPDISP]->display();
      xs = 0;
    }

    // text message on top, scrolling
    int len = strlen( scrolling);
    drawStringW(lmdp[TOPDISP], scrolling, len, xs, 0);

    // Toggle display of the new framebuffer
    lmdp[TOPDISP]->display();

    // Advance to next coordinate
    if( --xs < len * -8 ) 
      xs = TOPMATRIX_WIDTH;
  }

  // check for others update
  if( utime) {
    utime = 0;

    int i = dayn;
    lmdp[i]->clear();

    // update opening time
    drawStringN(lmdp[i], t_open, 5, 0, 0);

    // update closing time
    drawStringN(lmdp[i], t_clos, 5, 24, 0);

    // Toggle display of the new framebuffer
    lmdp[i]->display();
  }
  
}



/**
 * drawStringN - This function draws a string of the given length to the given position.
 * uses special Narrow font with only digits 0-9, space, :
 */
void drawStringN( LEDMatrixDriver* lmd, char* text, int len, int x, int y )
{
  for( int idx = 0; idx < len; idx ++ )
    {
      int c = text[idx];
      if( isdigit(c))
	c -= '0';
      else if( c == ':')
	c = 11;
      else
	c = 10;

      int w = pgm_read_byte( &(font[c][0]));
      for( uint8_t i=0; i<8; i++)
	font_char[i] = pgm_read_byte( &(font[c][i]));

      // only draw if char is visible
      if( 8 + x + idx * 8 > 0 ) {
	drawSprite( lmd, font_char, x, y, w, 8 );
      }
      x += w+1; 
    }
}

/**
 * drawStringW - This function draws a string of the given length to the given position.
 * uses full ascii uppercase font (characters 32-90)
 */
void drawStringW( LEDMatrixDriver* lmd, char* text, int len, int x, int y )
{
  for( int idx = 0; idx < len; idx ++ )
  {
    int c = toupper(text[idx]) - 32;

    // stop if char is outside visible area
    if( x + idx * 8  > TOPMATRIX_WIDTH )
      return;

    for( uint8_t i=0; i<8; i++)
      font_char[i] = pgm_read_byte( &(bigfont[c][i]));

    // only draw if char is visible
    if( 8 + x + idx * 8 > 0 )
      drawSprite( lmd, font_char, x + idx * 8, y, 8, 8 );
  }
}




/**
 * This draws a sprite to the given position using the width and height supplied (usually 8x8)
 */
void drawSprite( LEDMatrixDriver* lmd, byte* sprite, int x, int y, int width, int height )
{
  // The mask is used to get the column bit from the sprite row
  byte mask = B10000000;

  for( int iy = 0; iy < height; iy++ )
    {
      for( int ix = 0; ix < width; ix++ )
	{
	  lmd->setPixel(x + ix, y + iy, (bool)(sprite[iy] & mask ));

	  // shift the mask by one pixel to the right
	  mask = mask >> 1;
	}

      // reset column mask
      mask = B10000000;
    }
}

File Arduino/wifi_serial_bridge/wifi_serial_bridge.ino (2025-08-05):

//
// connect to eduroam wifi (no certificate)
// connect to sign (or other device) on 9600 baud serial (UART 2)
//
//

// on-board ESP32 LED
#define LED_PIN 2

#include <WiFi.h> //Wifi library
#include "esp_wpa2.h" //wpa2 library for connections to Enterprise networks
#include "arduino_percent.hpp"  // URL encode and decode

//Identity for user with password related to his realm (organization)
//Available option of anonymous identity for federation of RADIUS servers or 1st Domain RADIUS servers
#define EAP_ANONYMOUS_IDENTITY "" //anonymous@example.com, or you can use also nickname@example.com
#define EAP_IDENTITY "hazen@bu.edu" //nickname@example.com, at some organizations should work nickname only without realm, but it is not recommended
#define EAP_PASSWORD "Miata1994Z00mZ00m" //password for eduroam account
#define EAP_USERNAME "hazen@bu.edu" // the Username is the same as the Identity in most eduroam networks.

//SSID NAME
const char* ssid = "eduroam"; // eduroam SSID

char resp[100];

WiFiServer server(80);

String IpAddress2String(const IPAddress& ipAddress)
{
  return String(ipAddress[0]) + String(".") +\
  String(ipAddress[1]) + String(".") +\
  String(ipAddress[2]) + String(".") +\
  String(ipAddress[3])  ; 
}

void setup() {
  pinMode( LED_PIN, OUTPUT);

  Serial.begin(115200);
  Serial2.begin( 9600);
  delay(1000);
  Serial2.print( "M CONNECTING\n");
  delay(5000);
  Serial.print(F("Connecting to network: "));
  Serial.println(ssid);
  WiFi.disconnect(true);  //disconnect from WiFi to set new WiFi connection
 
  WiFi.begin(ssid, WPA2_AUTH_PEAP, EAP_IDENTITY, EAP_USERNAME, EAP_PASSWORD); // without CERTIFICATE, RADIUS server EXCEPTION "for old devices" required
  
  Serial.print("MAC: ");
  Serial.println( WiFi.macAddress());

  while (WiFi.status() != WL_CONNECTED) {
    delay(500);
    Serial.print(F("."));
  }
  Serial.println("");
  Serial.println(F("WiFi is connected!"));
  Serial.println(F("IP address set: "));
  Serial.println(WiFi.localIP()); //print LAN IP

  // convert IP address and display
  String ips = IpAddress2String( WiFi.localIP());
  snprintf( resp, sizeof(resp), "M %s\n", ips.c_str() );
  Serial2.print( resp);

  server.begin();
  delay(500);
}

//
// taken largely from SimpleWiFiServer example
//
void loop(){
 WiFiClient client = server.available();   // listen for incoming clients

  if (client) {                             // if you get a client,
    Serial.println("New Client.");           // print a message out the serial port
    String currentLine = "";                // make a String to hold incoming data from the client
    while (client.connected()) {            // loop while the client's connected
      if (client.available()) {             // if there's bytes to read from the client,
        char c = client.read();             // read a byte, then
        Serial.write(c);                    // print it out the serial monitor
        if (c == '\n') {                    // if the byte is a newline character

          // if the current line is blank, you got two newline characters in a row.
          // that's the end of the client HTTP request, so send a response:
          if (currentLine.length() == 0) {
            // HTTP headers always start with a response code (e.g. HTTP/1.1 200 OK)
            // and a content-type so the client knows what's coming, then a blank line:
            client.println("HTTP/1.1 200 OK");
            client.println("Content-type:text/html");
            client.println();

            // the content of the HTTP response follows the header:
            client.print("Click <a href=\"/H\">here</a> to turn the LED on pin 5 on.<br>");
            client.print("Click <a href=\"/L\">here</a> to turn the LED on pin 5 off.<br>");

            // The HTTP response ends with another blank line:
            client.println();
            // break out of the while loop:
            break;
          } else {    // process line and erase it
	    // look for queries headed to us
	    const char *qry = currentLine.c_str();
	    if( !strncmp( qry, "GET /CMD=", 9)) {
	      // unencode the command and send to arduino
	      percent::decode( qry+9, resp);
	      // check for and strip HTTP thing
	      char *p = strrchr( resp, ' ');   // look for space at end
	      if( p)			       // overwrite with null
		*p = '\0';
	      strcat( resp, "\n");
	      Serial2.print( resp);
	    }
            currentLine = "";
          }
        } else if (c != '\r') {  // if you got anything else but a carriage return character,
          currentLine += c;      // add it to the end of the currentLine
        }



        // Check to see if the client request was "GET /H" or "GET /L":
        if (currentLine.endsWith("GET /H")) {
          digitalWrite(LED_PIN, HIGH);               // GET /H turns the LED on
        }
        if (currentLine.endsWith("GET /L")) {
          digitalWrite(LED_PIN, LOW);                // GET /L turns the LED off
        }
      }
    }
    // close the connection:
    client.stop();
    Serial.println("Client Disconnected.");
  }
  
}

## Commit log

2024-02-13 multi-digit prototype
    [7seg-mech.scad]
2024-03-02 starting on schematic
    [#layout_8x8.dxf, 8x24_example.ods, digit_8x9.kicad_pcb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]
2024-03-02 schematic work
    [#layout_8x8.dxf, digit_8x9.kicad_sch, layout_8x8.dxf]
2024-03-02 Atmega version
    [digit_8x9-B_Cu.gbr, digit_8x9-B_Mask.gbr, digit_8x9-B_Silkscreen.gbr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]
2024-03-03 Arduino test for 8x24 matrix
    [layout_8x8.dxf]
2024-03-06 working on drawing
    [layout_8x8.dxf]
2024-03-11 updated board holder
    [display_standoffs.scad, display_standoffs.stl, display_support.scad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]
2024-03-23 update holder
    [cut_back.dxf, cut_back_holes.dxf, cut_front.dxf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]
2024-04-19 multi-display shield board
    [display_standoffs2.stl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]
2024-05-08 working on software
    [8display_standoffs.stl, display_standoffs.scad]
2024-05-10 Add gerbers as built, update README
    [multi_display_shield-B_Cu.gbr, multi_display_shield-B_Mask.gbr, multi_display_shield-B_Silkscreen.gbr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]
2024-07-11 software and box
    [#arduino_box_all.dxf, Arduino UNO R3 shield - full.dxf, arduino_box.scad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]
2024-07-23 Clean up laser cut files
    [cut_back.dxf, cut_back_with_outline.dxf, cut_front.dxf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]
2025-08-05 add new box, update software
    [2.54 mm DUPONT MALE PIN HEADER, IO, 2X20, RPi4ModelB.SLDPRT, 2.54 mm DUPONT MALE PIN HEADER, IO, 2X40, RPi4ModelB.SLDPRT, 2.54 mm DUPONT MALE PIN HEADER, POE, 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]
